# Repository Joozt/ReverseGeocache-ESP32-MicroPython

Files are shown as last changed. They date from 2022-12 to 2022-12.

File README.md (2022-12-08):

# Reverse Geocache using an ESP32 with MicroPython

A reverse geocache is a present in a box that only opens at a certain physical location. Finding the location requires a little puzzling, because the box will only show the distance to the location. Normally a [geocache](https://en.wikipedia.org/wiki/Geocaching) is a treasure hunt puzzle that brings you to a location where you find a hidden container, but with a reverse geocache you bring the container with you.

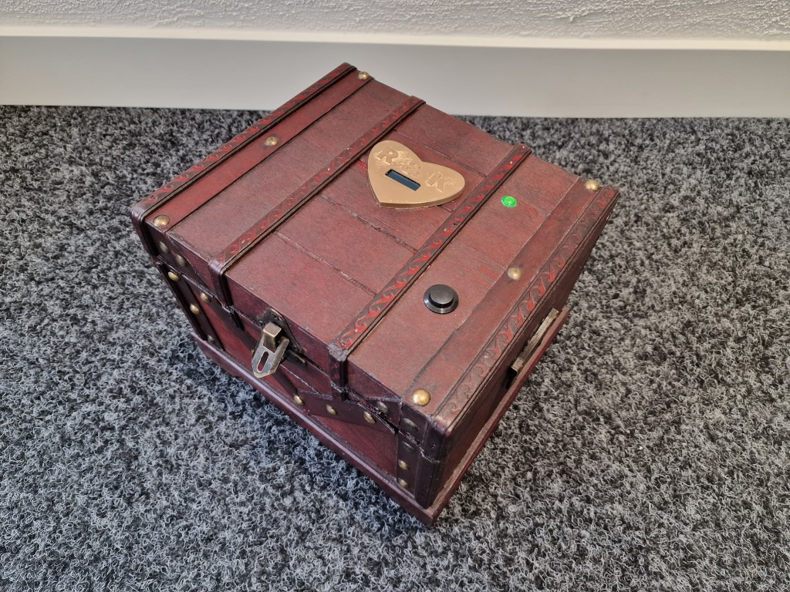
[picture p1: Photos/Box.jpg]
Reverse Geocache box


The original idea comes from [Mikal Hart](http://arduiniana.org/projects/the-reverse-geo-cache-puzzle/) and several [clones](https://learn.adafruit.com/reverse-geocache-engagement-box?view=all) can be found around the internet. This variant is inspired by the other reverse geocaches, but is implemented in [MicroPython](https://en.wikipedia.org/wiki/MicroPython) on an [ESP32 microcontroller](https://en.wikipedia.org/wiki/ESP32).

## Parts
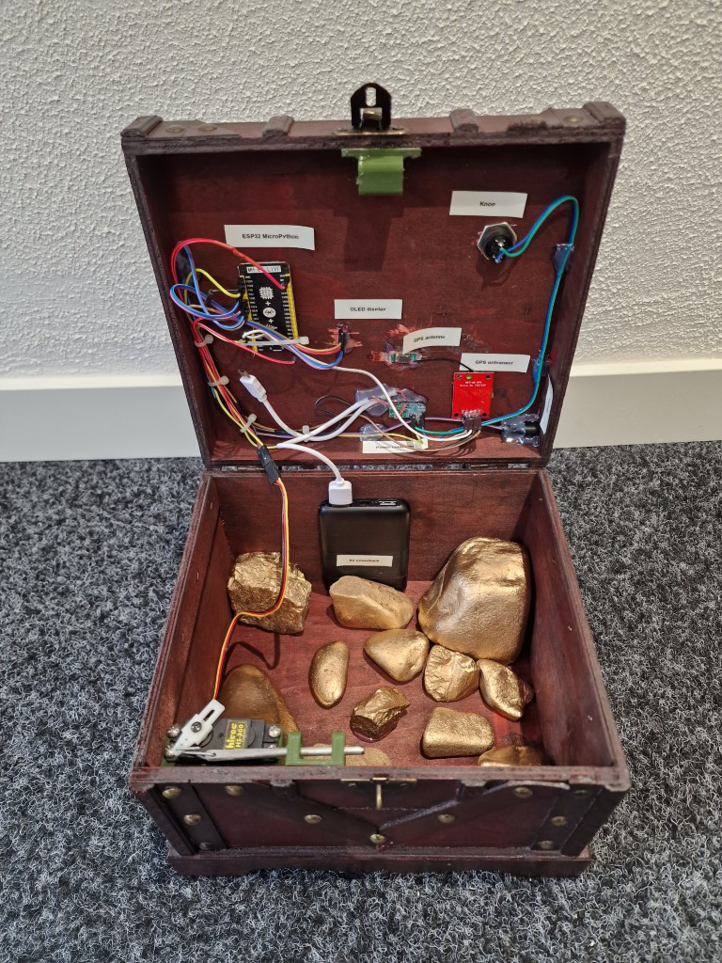
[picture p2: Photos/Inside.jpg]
Reverse Geocache inside


 - [Box](https://www.amazon.com/dp/B07CMYPQVV)
 - [ESP32 development board](https://aliexpress.com/wholesale?SearchText=MH-ET+Live+ESP32)
 - [Servo](https://aliexpress.com/wholesale?SearchText=servo)
 - [GPS receiver](https://aliexpress.com/wholesale?SearchText=NEO-6M)
 - [Display](https://aliexpress.com/wholesale?SearchText=128X32+Oled)
 - [Button](https://aliexpress.com/wholesale?SearchText=momentary+push+button)
 - [Power controller](https://sparkfun.com/products/8903)
 - Powerbank
 - [Dupont wires](https://aliexpress.com/wholesale?SearchText=dupont+wires)
 - [3D printed lock mechanism](https://www.thingiverse.com/thing:5689225)

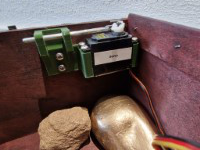
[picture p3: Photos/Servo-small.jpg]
Lock servo
 
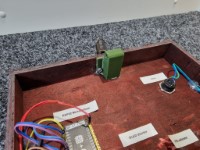
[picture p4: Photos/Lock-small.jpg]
Lock
 

 ## Working
 After building the box, the present can be put inside. Before wrapping it in gift paper, the button has to be pushed once. This will engage the lock. 
 
 When the present is unwrapped, the person doesn't know what it is and will push the button. It will show a welcome message and play a tune. Then it will start searching for GPS signals. It will search for 5 minutes before turning off. During the next attempts it will show a message that you have to be patient and even outdoors it can take a couple of minutes.

 When a GPS signal is found, it will show the distance to the destination (10m precision). It will keep updating the distance when moving, but it will turn off after 1 minute to make it is not _too_ easy to find the destination. The LED from the GPS receiver will start blinking, which can be positioned in front of a LED lens/cap so that it is visible to the user.
 
 It shows how many attempts were made. Maximum 50 attempts are allowed. After 50 attempts it shows a failure message and play a sad tune. But after waiting 10 seconds the program continues, so that it is still possible to find the destination and unlock the box.

 When the distance is less than 20 meters from the configured destination, it will show that the location is found and the next location has to be discovered. The person doesn't know how many locations will follow, but the number of remaining attempts keeps decreasing.

 After the second destination has been found, the puzzle is complete. It will open the lock, play a winning tune and display a congratulations message. After that it will show a greetings message and turn off after 1 minute.

 After completing the puzzle, next time it is turned on it will immediately play the winning tune, display the congratulations and greeting messages and turn off.

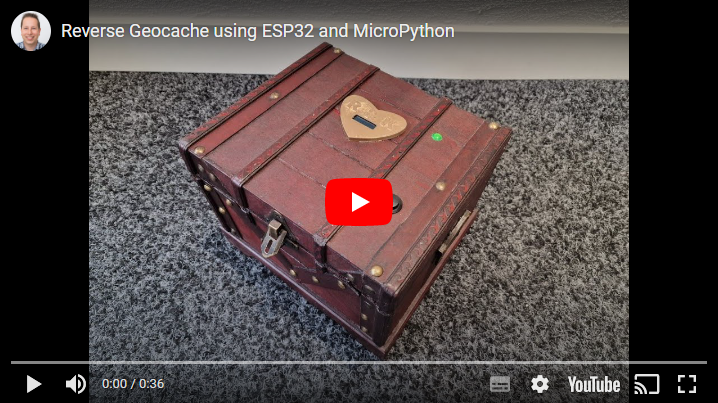
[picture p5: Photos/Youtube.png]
YouTube (https://youtu.be/wEcFw1qeKLA)
 

 ## Schematic
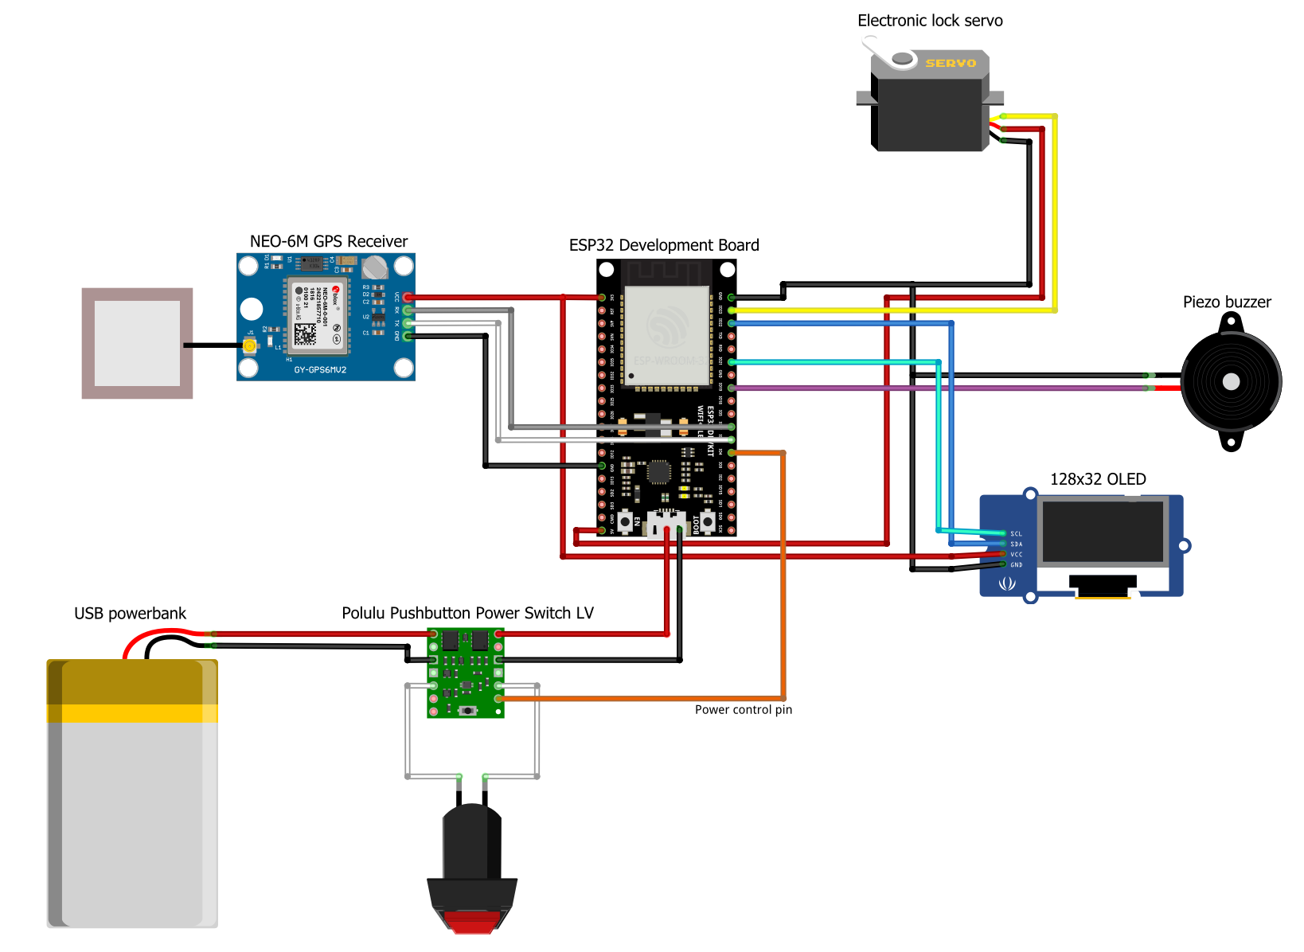
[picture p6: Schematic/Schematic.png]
Schematic
 

 ## Messages
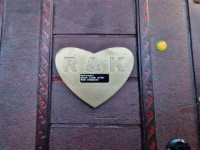
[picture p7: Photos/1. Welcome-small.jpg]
Welcome
 
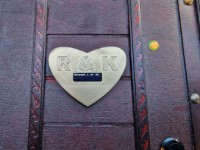
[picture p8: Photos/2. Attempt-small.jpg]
Attempt
 
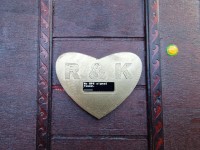
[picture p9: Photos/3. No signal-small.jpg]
No signal
 
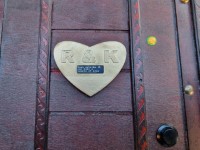
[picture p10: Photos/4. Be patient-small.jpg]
Be patient
 
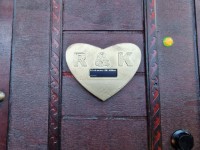
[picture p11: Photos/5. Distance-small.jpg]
Distance
 
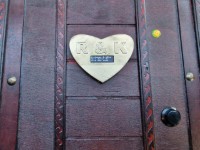
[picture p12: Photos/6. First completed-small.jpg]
First completed
 
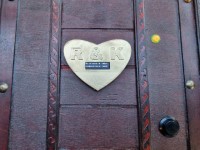
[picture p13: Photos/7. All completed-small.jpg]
All completed
 
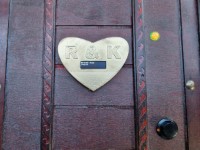
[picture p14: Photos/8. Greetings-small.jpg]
Greetings
 
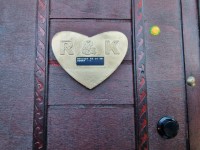
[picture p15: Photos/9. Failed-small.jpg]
Failed


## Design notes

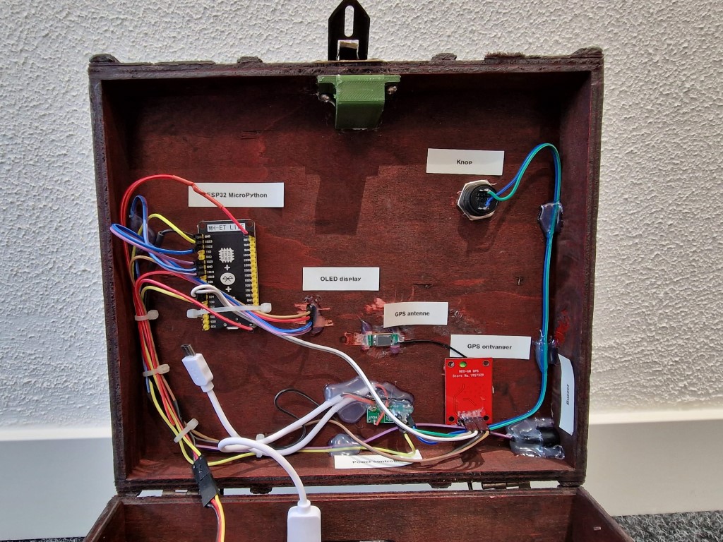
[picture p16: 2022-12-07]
Photos/Electronics.jpg

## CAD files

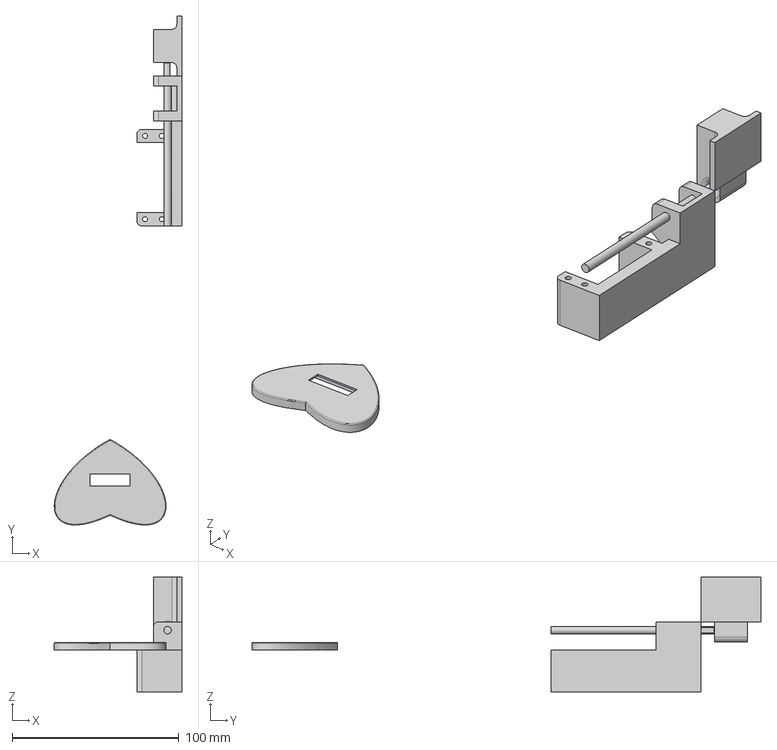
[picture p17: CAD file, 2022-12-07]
3D Print/Reverse Geocache.step
76.6 x 305.6 x 68.8 mm

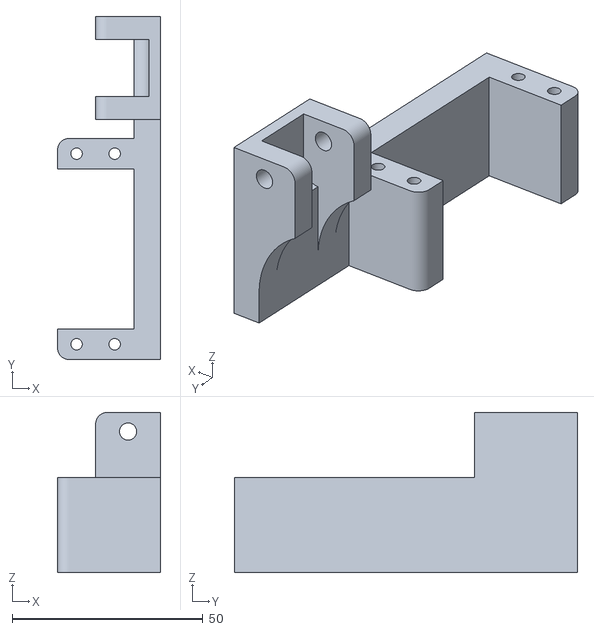
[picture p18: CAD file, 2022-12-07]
3D Print/Servo mount.stl
27.0 x 90.0 x 42.0

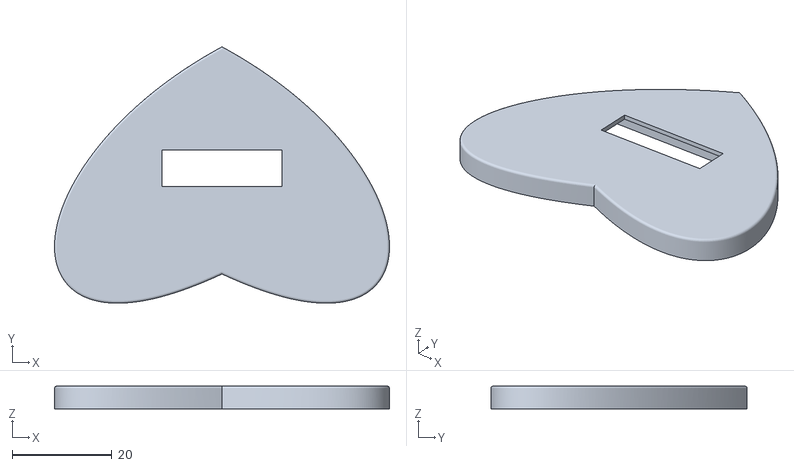
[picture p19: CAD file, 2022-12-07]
3D Print/Heart screen cover.stl
67.1 x 51.4 x 4.60

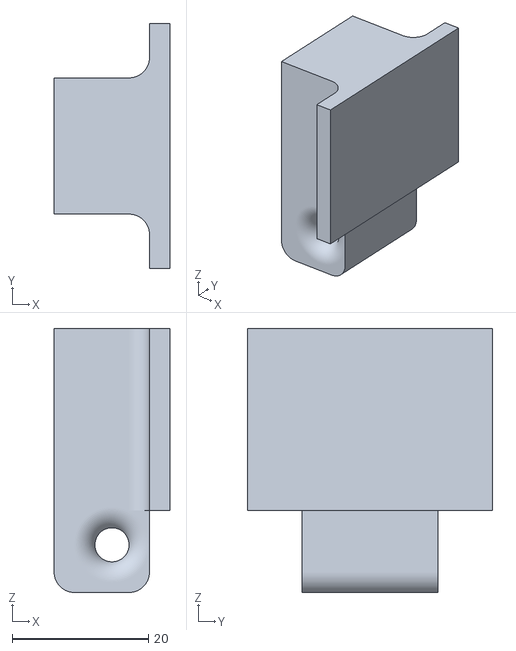
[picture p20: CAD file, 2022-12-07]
3D Print/Lock.stl
17.0 x 36.0 x 38.8

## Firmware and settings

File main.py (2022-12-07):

from time import sleep, time
from math import radians, cos, sin, atan2, sqrt
from machine import Pin, SoftI2C, PWM, UART
from ssd1306 import SSD1306_I2C
from rtttl import RTTTL

# Coordinates can be copied from Google Maps (use satellite view for better results)
FIRST_DESTINATION_LAT = 52.37823186700114
FIRST_DESTINATION_LON = 4.899774671697002
SECOND_DESTINATION_LAT = 51.92339875478843
SECOND_DESTINATION_LON = 4.470300454531137
MAX_NUMBER_OF_ATTEMPTS = 50
MAX_DISTANCE_KM_TO_DESTINATIONS = 0.02
SECONDS_UNTIL_SHOWING_NO_GPS_MESSAGE = 30
SECONDS_UNTIL_SHOWING_BE_PATIENT_MESSAGE = 60
SECONDS_UNTIL_TURNING_OFF_AFTER_GPS_FOUND = 60
SECONDS_UNTIL_TURNING_OFF_WHEN_NO_GPS_FOUND = 300

class State:
    INIT = 0
    WELCOME = 1
    NO_ATTEMPTS_REMAINING = 2
    SEARCHING_GPS = 3
    GPS_FIX_FOUND = 4
    NO_GPS_FIX_FOUND = 5
    BE_PATIENT = 6
    NOT_CLOSEBY = 7
    SINGLE_COMPLETED = 8
    ALL_COMPLETED = 9
    GREETINGS = 10

class LocationCompleted:
    NONE = 0
    FIRST = 1
    SECOND = 2

state = State.INIT
location_completed = LocationCompleted.NONE
destination_lat = FIRST_DESTINATION_LAT
destination_lon = FIRST_DESTINATION_LON
attempt_count = 0
progress_bar_value = 0
distance_km = -1
latitude = 0.0
longitude = 0.0
gps_time = ''
no_gps_message_time = time() + SECONDS_UNTIL_SHOWING_NO_GPS_MESSAGE
be_patient_message_time = time() + SECONDS_UNTIL_SHOWING_BE_PATIENT_MESSAGE
be_patient_message_end_time = time() + SECONDS_UNTIL_SHOWING_BE_PATIENT_MESSAGE + SECONDS_UNTIL_SHOWING_NO_GPS_MESSAGE
distance_showing_time = 0
attempt_time = time() + SECONDS_UNTIL_TURNING_OFF_WHEN_NO_GPS_FOUND

gps_module = UART(2, baudrate=9600, timeout=1000)
display = SSD1306_I2C(width=128, height=32, i2c=SoftI2C(scl=Pin(22), sda=Pin(21)))
buzzer = PWM(Pin(19), duty=0)
servo_lock = PWM(Pin(23), freq=50, duty=60) # Initiate in closed state
power_control = Pin(4, Pin.OUT, Pin.PULL_DOWN)

def play_tune(tune):
    rtttl = RTTTL(tune)
    for freq, msec in rtttl.notes():
        if freq > 0:
            buzzer.freq(int(freq))
            buzzer.duty(512)
        sleep(msec*0.0006)
        buzzer.duty(0)
        sleep(0.025)

def play_start_tune():
    play_tune('Mission Impossible:d=16,o=6,b=95:32d,32d#,32d,32d#,32d,32d#,32d,32d#,32d,32d,32d#,32e,32f,32f#,32g,g,8p,g,8p,a#,p,c7,p,g,8p,g,8p,f,p,f#,p,g,8p,g,8p,a#,p,c7,p,g,8p,g,8p')

def play_winning_tune():
    play_tune('A-Team:d=8,o=5,b=125:4d#6,a#,2d#6,16p,g#,4a#,4d#.,p,16g,16a#,d#6,a#,f6,2d#6,16p,c#.6,16c6,16a#,g#.,2a#')

def play_losing_tune():
    play_tune('Lost:d=8,o=5,b=300:d#,c#,c,1a#4')

def show_welcome():
    display.fill(0)
    display.text('Welcome!', 0, 0)
    display.text('Good luck with', 0, 10)
    display.text('the puzzle!', 0, 20)
    display.show()

def show_attempt():
    display.fill(0)
    display.text('Attempt {} of {}'.format(attempt_count, MAX_NUMBER_OF_ATTEMPTS), 0, 0)
    display.show()

def show_distance():
    display.fill(0)
    display.text("Distance:{:.2f}km".format(distance_km), 0, 0)
    show_progress_bar()
    display.show()

def update_progress_bar():
    global progress_bar_value
    if progress_bar_value == 128:
        progress_bar_value = 0
    show_progress_bar()
    display.show()
    progress_bar_value += 1

def show_progress_bar():
    for x in range(128):
        display.pixel(x, 31, x < progress_bar_value)

def show_no_gps():
    display.fill(0)
    display.text('No GPS signal', 0, 0)
    display.text('found.', 0, 10)
    show_progress_bar()
    display.show()

def show_be_patient():
    display.fill(0)
    display.text('Even outside it', 0, 0)
    display.text('can take a', 0, 10)
    display.text('couple of mins', 0, 20)
    show_progress_bar()
    display.show()

def show_failed():
    display.text('SORRY :-(', 0, 10)
    display.show()

def show_single_completed():
    display.fill(0)
    display.text("Distance:{:.2f}km".format(distance_km), 0, 0)
    display.text('Well done! On', 0, 10)
    display.text('with the next...', 0, 20)
    display.show()

def show_all_completed():
    display.fill(0)
    if distance_km >= 0.0:
        display.text("Distance:{:.2f}km".format(distance_km), 0, 0)
    display.text('CONGRATULATIONS!', 0, 15)
    display.show()

def show_greetings():
    display.fill(0)
    display.text("Greetings", 0, 0)
    display.text("from", 0, 10)
    display.text("Joozt", 0, 20)
    display.show()

def read_attempt_counter():
    global attempt_count
    file = open('counter.txt')
    attempt_count = int(file.read())
    print("Count: {}".format(attempt_count))
    file.close()

def increment_attempt_counter():
    global attempt_count
    attempt_count += 1
    file = open('counter.txt', 'w')
    file.write(str(attempt_count))
    file.close()

def write_current_location():
    file = open('locations.txt', 'a')
    file.write("{} https://maps.google.com/?q={},{}\n".format(gps_time, latitude, longitude))
    file.close()

def servo_lock_open():
    servo_lock.duty(100)

def read_location_completed():
    global location_completed
    file = open('completed.txt')
    location_completed = int(file.read())
    print("Completed: {}".format(location_completed))
    file.close()
    update_destination()

def increment_location_completed():
    global location_completed
    location_completed += 1
    file = open('completed.txt', 'w')
    file.write(str(location_completed))
    file.close()
    update_destination()

def update_destination():
    global destination_lat, destination_lon
    if location_completed == LocationCompleted.NONE:
        destination_lat = FIRST_DESTINATION_LAT
        destination_lon = FIRST_DESTINATION_LON
    if location_completed == LocationCompleted.FIRST:
        destination_lat = SECOND_DESTINATION_LAT
        destination_lon = SECOND_DESTINATION_LON

def turn_off():
    power_control.on()
    # display.poweroff()
    # while True:
    #     sleep(1)

def get_distance_km():
    global distance_km, latitude, longitude, gps_time
    line = str(gps_module.readline())
    parts = line.split(',')
    if (len(parts) == 15 and parts[0] == "b'$GPGGA"):
        if(parts[1] and parts[2] and parts[3] and parts[4] and parts[5] and parts[6] and parts[7]):
            print(line)
            latitude = convert_to_degrees(parts[2])
            if parts[3] == 'S':
                latitude = -float(latitude)
            longitude = convert_to_degrees(parts[4])
            if parts[5] == 'W':
                longitude = -float(longitude)
            satellites = int(parts[7])
            distance_km = calculate_distance_km(destination_lat, destination_lon, latitude, longitude)
            gps_time = parts[1][0:2] + ":" + parts[1][2:4] + ":" + parts[1][4:6]
            print("----------------------")
            print("Latitude: {}".format(latitude))
            print("Longitude: {}".format(longitude))
            print("Satellites: {}".format(satellites))
            print("Distance: {:.2f}km".format(distance_km))
            print("Time: {}".format(gps_time))
            print("----------------------")

def convert_to_degrees(rawDegrees):
    rawAsFloat = float(rawDegrees)
    firstDigits = int(rawAsFloat/100)
    nextTwoDigits = rawAsFloat - float(firstDigits*100)
    converted = float(firstDigits + nextTwoDigits/60.0)
    converted = '{0:.6f}'.format(converted)
    return float(converted)

def calculate_distance_km(lat1, lon1, lat2, lon2):
    phi1, phi2 = radians(lat1), radians(lat2)
    dphi       = radians(lat2 - lat1)
    dlambda    = radians(lon2 - lon1)
    a = sin(dphi/2) ** 2 + cos(phi1) * cos(phi2) * sin(dlambda/2) ** 2
    return 2 * 6372.8 * atan2(sqrt(a), sqrt(1 - a))


def game_loop():
    global state, distance_km, distance_showing_time

    if state == State.INIT:
        read_location_completed()
        if location_completed >= LocationCompleted.SECOND:
            state = State.ALL_COMPLETED
        else:
            read_attempt_counter()
            increment_attempt_counter()
            if attempt_count > MAX_NUMBER_OF_ATTEMPTS:
                state = State.NO_ATTEMPTS_REMAINING
            else:
                state = State.WELCOME

    if state == State.NO_ATTEMPTS_REMAINING:
        show_attempt()
        show_failed()
        play_losing_tune()
        sleep(10)
        state = State.SEARCHING_GPS # Continue anyway

    if state == State.WELCOME:
        show_welcome()
        play_start_tune()
        show_attempt()
        sleep(4)
        state = State.SEARCHING_GPS

    if state == State.SEARCHING_GPS:
        get_distance_km()
        update_progress_bar()
        if distance_km >= 0.0:
            state = State.GPS_FIX_FOUND
        else:
            if time() > be_patient_message_time and time() < be_patient_message_end_time and attempt_count >= 2 and attempt_count <= 7:
                state = State.BE_PATIENT
            elif time() > no_gps_message_time:
                state = State.NO_GPS_FIX_FOUND

    if state == State.GPS_FIX_FOUND:
        if distance_showing_time == 0:
            write_current_location()
            distance_showing_time = time() + SECONDS_UNTIL_TURNING_OFF_AFTER_GPS_FOUND
        if time() > distance_showing_time:
            turn_off()

        show_distance()
        if distance_km < MAX_DISTANCE_KM_TO_DESTINATIONS:
            state = State.SINGLE_COMPLETED
        else:
            get_distance_km()
            update_progress_bar()

    if state == State.NO_GPS_FIX_FOUND:
        show_no_gps()
        state = State.SEARCHING_GPS

    if state == State.BE_PATIENT:
        show_be_patient()
        state = State.SEARCHING_GPS

    if state == State.SINGLE_COMPLETED:
        increment_location_completed()
        if location_completed >= LocationCompleted.SECOND:
            state = State.ALL_COMPLETED
        else:
            show_single_completed()
            play_start_tune()
            sleep(10)
            distance_km = -1
            state = State.SEARCHING_GPS

    if state == State.ALL_COMPLETED:
        servo_lock_open()
        show_all_completed()
        play_winning_tune()
        sleep(10)
        state = State.GREETINGS

    if state == State.GREETINGS:
        show_greetings()
        sleep(60)
        turn_off()

    if time() > attempt_time:
        turn_off()


while True:
    game_loop()

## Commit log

2022-12-07 Reverse Geocache in MicroPython
    [Heart screen cover.stl, Lock.stl, Reverse Geocache.step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]
2022-12-08 Add schematic and improve readme
    [Reverse Geocache - Fritzing.fzz]
